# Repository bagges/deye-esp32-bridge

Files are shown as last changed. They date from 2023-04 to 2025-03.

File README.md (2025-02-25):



# deye-esp32-bridge

This PCB and Software is used to create a board which communicates with your Deye/Sunsynk inverter and also the BMS of your battery (SeplosBMS and PaceBMS are supported for now).



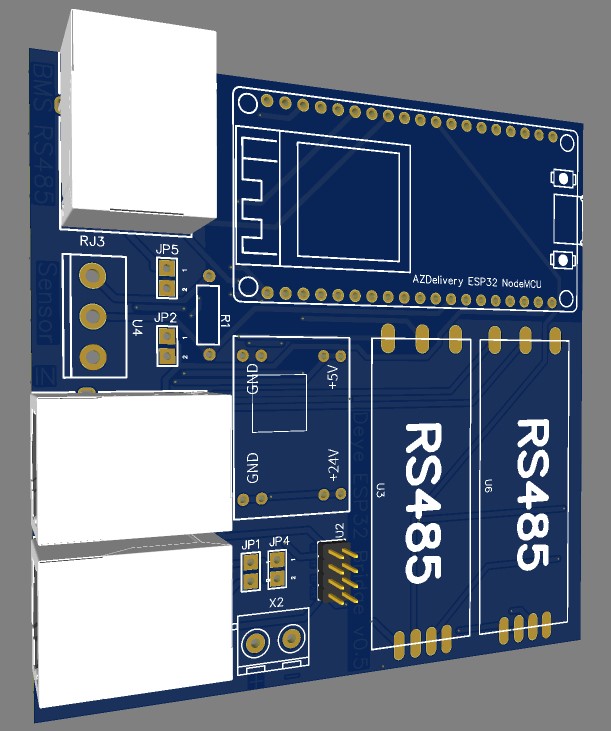
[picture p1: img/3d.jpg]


# BOM
 - [PCB (designed with easyeda and produced by jlcpcb)](https://www.makeiton.de/produkt-kategorie/bauteile/)
 - [AZDelivery ESP32 Dev v4](https://amzn.to/41Sd0v4)
 - [2x RS485 Serial Converter](https://amzn.to/3L1OmBq)
 - [DC/DC Step Down Module](https://amzn.to/3oFFiur)
 - [3x RJ45 connectors](https://amzn.to/3AqmPo8)
 - [12V din rail power supply](https://amzn.to/3VNIEYH)

# Prepare RS485 Serial Converter
Make sure that your RS485 converter is terminated by about 120R. 
Measure the resistance between B- and A+. Should be something between 110-130 Ohms. 
If you cannot measure any resistance, you need to shorten the the two small pins next to the B- connector. 
On my boards it was labled with R13.

# Deye Setup
 - Goto Advanced Function and set to Slave and Modbus SN 01

# Flash ESP32
 - Adapt your wifi settings in the secrets.yaml
 - Connect your PC to the micro USB and run: ```esphome run deye-esp32-bridge.yaml```

# Wiring
 - Connect any 7-24V DC source to the screw headers (do not use CN2 PINS 7+8 from deye inverter, they only work for about 100mA). Make sure that JP2 is closed.
 - As an alternative you can connect directly to the USB of the ESP32. Make sure that JP2 is not closed. This method makes often problems with the RS485 connection.
 - Connect your inverters BMS RJ45 to the CAN IN RJ45 of the PCB.
 - If you want to connect your inverter and BMS via CAN. connect your BMS to the BMS IN RJ45 of the PCB.
 - Connect your Seplos BMS to RJ3
 - I used RJ45 cables without shield connected to the RJ45 connector

## Component Description
| Component | Function |
|---|---|
| JP1 | If closed, connects GND from Deye to GND of the BMS |
| JP2 | If closed, connects the DCDC Converter to the ESP32 |
| JP4 | If closed, connects GND from Deye to GND of the PCB |
| JP5 | If closed, connects GND from the BMS to GND of the PCB |
| U2 | Additional general purpose I/O / GND / 5V / 3V3 |
| R1 | Optional resistor, needed if connecting DS18B20 to U4  |
| RJ1 | Connects to the BMS port of Deye |
| RJ2 | Connects to the CAN Port of the BMS |
| RJ3 | Connects to the RS485 Port of the BMS |

# Software
 - The esphome configuration file for deye is based on the work of klatremis (https://github.com/klatremis/esphome-for-deye)
 - The esphome configuration file for seplos is based on the work of syssi (https://github.com/syssi/esphome-seplos-bms)
 
# Disclaimer

This repository contains files for demonstration purposes only. Use the files on your own risk. I am not responsible for any damage!

# License

Shield: [][cc-by-nc-sa]

This work is licensed under a
[Creative Commons Attribution-NonCommercial-ShareAlike 4.0 International License][cc-by-nc-sa].

[][cc-by-nc-sa]

[cc-by-nc-sa]: http://creativecommons.org/licenses/by-nc-sa/4.0/
[cc-by-nc-sa-image]: https://licensebuttons.net/l/by-nc-sa/4.0/88x31.png
[cc-by-nc-sa-shield]: https://img.shields.io/badge/License-CC%20BY--NC--SA%204.0-lightgrey.svg

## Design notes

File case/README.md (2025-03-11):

# Modified 3D Printed Case

I had a few changes that i wanted to do to the Case so i turned the stl's of the existing case into CAD files and made a few changes that some might like aswell and i think having options is better then not having them :D. So here you go. Below are some Pictures.

### Changes to the Bottom of the Case
The PCB's that I ordered were 2mm thick instead of the Standard ~1.5mm. So i adjusted the depth where the pcb sits in to accomodate the 2mm thick PCB's.

Additionally I like to use Heatset inserts instead of screwing into the plastic, but the previous holes were only 4mm. So i adjusted them to 4.7mm which is the perfect size for M3 Heatsets when printed in ABS. Should still work for PLA and other Materials.
### Changes to the Top of the Case
There was not really anything that needed changing, but I was not a fan of the MARK 4 Label and i wanted to lable the diffrent ports instead. So that's what i did, I added lables for the 3 Rj45 Ports, the Temperature sensor, + and - for the power Terminal aswell as a USB logo for the USB port of the ESP32.
To Fit the Lables a bit better, I made the cutouts for the screw Terminals a little bit smaller. Everything is still accessible.

You have a few options of how to print this:
- Print only the 'top.stl' and have the text and logo's engraved into the printed piece.
- Print it in multiple colors by importing all the stl files from the Folder 'MultiColor options' aswell as the top.stl from the 'top' folder at the same time and selecting 'yes' when asked if you want to import all the files as a Single Object with multiple Parts. If you do this, the logos will be automatically placed in the engraved parts of the case. If you do not do this, the logos will all just be put into the center of the slicer. (only works when the slicer is setup for Multi color Printing, otherwise it does not ask the question). This way you can give each of the Lables a diffrent color, i find this the best option to use myself.
- Print it in multiple colors by using the file 'top_with_labels_multicolor_split_to_parts.stl' from the subfolder 'Single_multicolor_file' under 'MultiColor options' and right clicking it in the Slicer and click 'split to multiple parts' and coloring each file as you like. This has the problem/benefit depending on how you view it, that it splits the text into its individual letters, so you could color each letter the word "BMS" in a diffrent color. Might be useful for someone, but i find this a bit cumbersome, but this way you only need to download one file instead of multiple.

I made a Picture as an example, with alot of colors, i only printed it in Black with green Logos, but you can customize or print in whatever combination of colors as you like.

### Multicolor
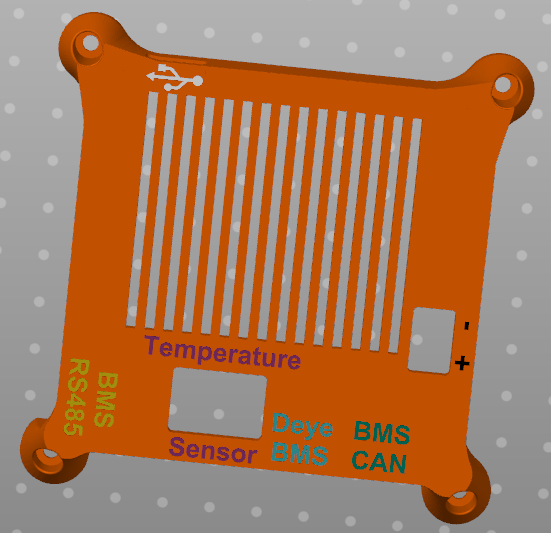
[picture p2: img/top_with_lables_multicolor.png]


### No Color, just engraved
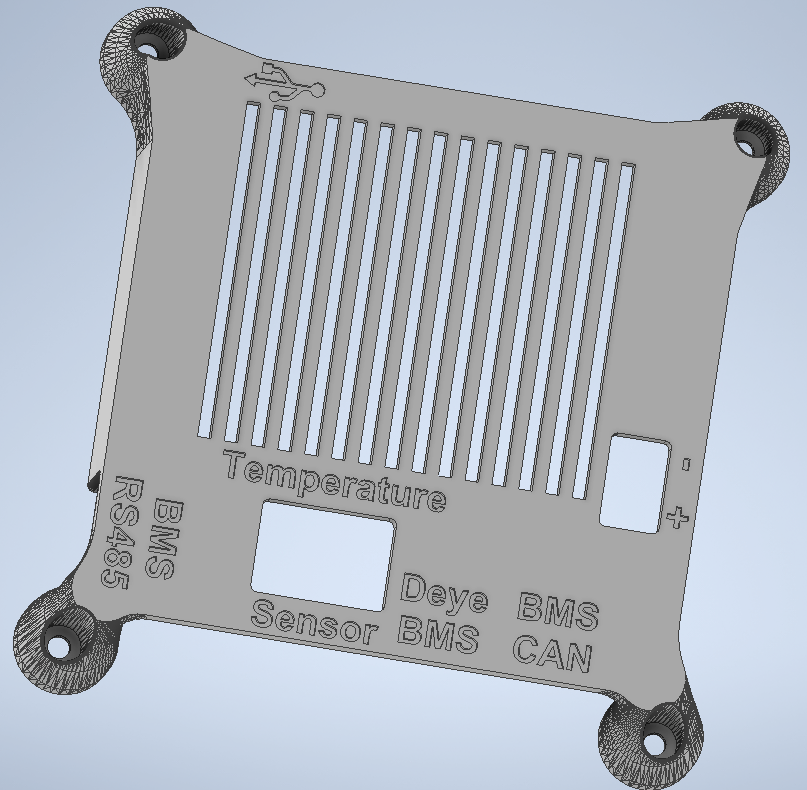
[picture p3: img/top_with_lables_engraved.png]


##### Case modified by:
- [xF4m3](https://github.com/xF4m3 "xF4m3")

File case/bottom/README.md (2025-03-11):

# Bottom Part of the Case for standard thickness PCB's

This is probably the bottom part of the case most of you will be printing, this is for standard size PCB's with a thickness of ~1.5mm.

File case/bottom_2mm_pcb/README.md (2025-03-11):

# Bottom Part of the Case for 2mm thick PCB's

In case your PCB does not have the standard thickness of ~1.5mm you can use this version to accomodate a 2mm thick PCB.

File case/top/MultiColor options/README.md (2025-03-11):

# MultiColor with Multiple Files

Stl's in this folder are all the Text and Logos. To use them you also need the top.stl fle together with all the stl's in this folder. Below is a description of how to do the Multicolored print.

- Print it in multiple colors by importing all the stl files from this folder aswell as the "top.stl" file from a folder higher up at the same time and selecting 'yes' when asked if you want to import all the files as a Single Object with multiple Parts. If you do this, the logos will be automatically placed in the engraved parts of the case. If you do not do this, the logos will all just be put into the center of the slicer and aligning will be difficult. (this only works when the slicer is setup for Multi color Printing, otherwise it does not ask the question). This way you can give each of the Lables a diffrent color, i find this the best option to use myself.

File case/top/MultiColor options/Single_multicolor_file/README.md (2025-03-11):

# Single Multicolor File

This file includes everything, the top.stl and all the logo and text stls as one object. See below for how to Print this with multiple colors.

- Print it in multiple colors by using the file 'top_with_labels_multicolor_split_to_parts.stl' from the this Folder and right clicking it in the Slicer and click 'split to multiple parts' and coloring each file as you like. This has the problem/benefit depending on how you view it, that it splits the text into its individual letters, so you could color each letter the word "BMS" in a diffrent color. Might be useful for someone, but i find this a bit cumbersome, but this way you only need to download one file instead of multiple.

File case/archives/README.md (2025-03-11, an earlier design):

# Previous version of the Case without any labes. It does have a "Mark 4" Logo instead.

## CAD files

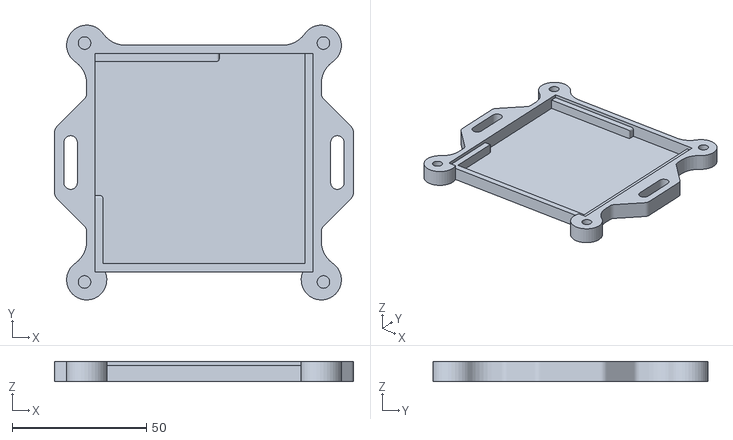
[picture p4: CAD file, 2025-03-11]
case/bottom/bottom.stl
111.4 x 102.4 x 7.50

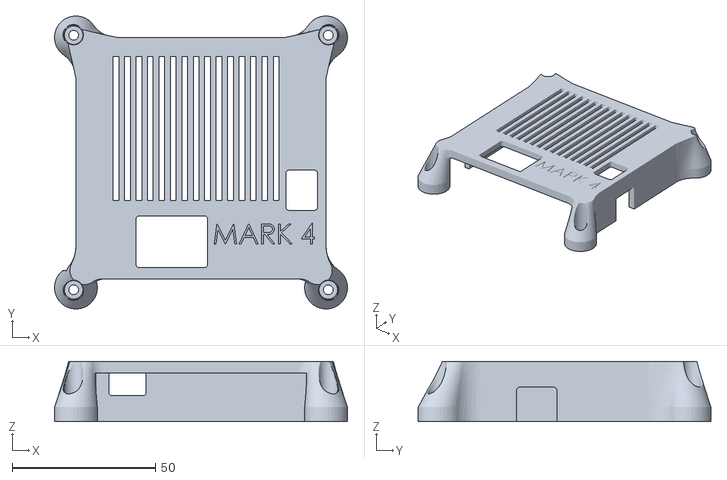
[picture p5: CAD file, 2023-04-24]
case/top.STL
102.4 x 102.4 x 21.0

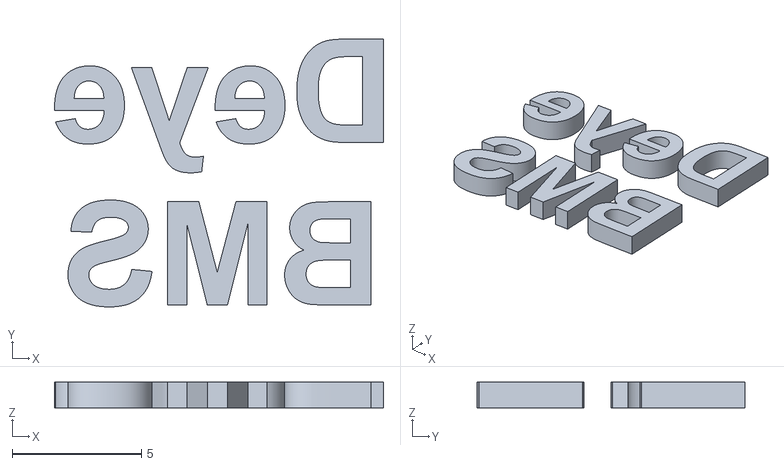
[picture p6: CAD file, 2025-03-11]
case/top/MultiColor options/deye_bms_text.stl
12.7 x 10.4 x 1.00

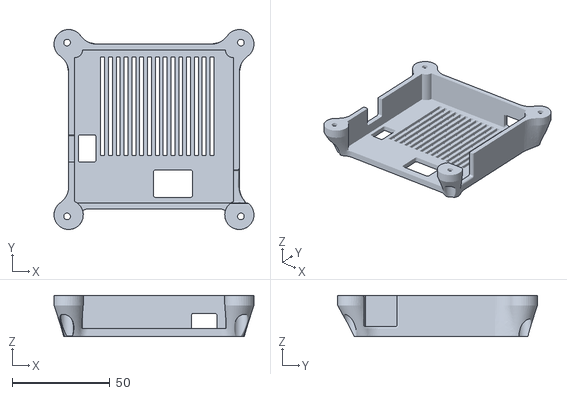
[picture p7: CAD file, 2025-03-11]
case/top/top.stl
102.4 x 102.4 x 21.0

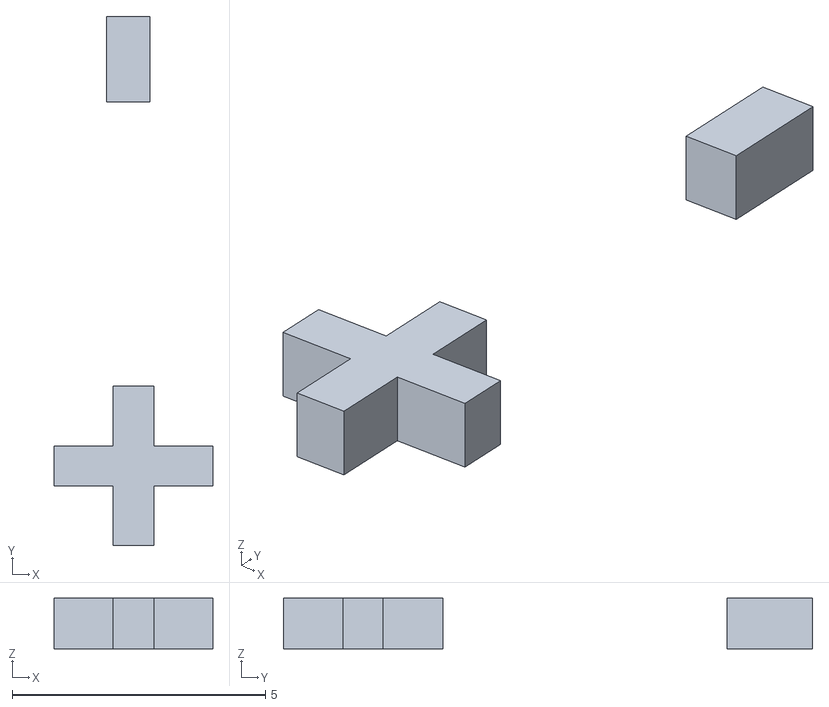
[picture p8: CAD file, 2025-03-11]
case/top/MultiColor options/24V_logo.stl
3.14 x 10.4 x 1.00

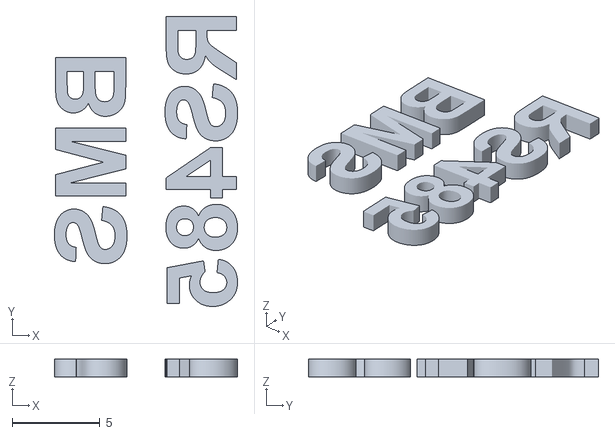
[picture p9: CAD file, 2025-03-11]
case/top/MultiColor options/bms_rs485_text.stl
10.4 x 16.5 x 1.00

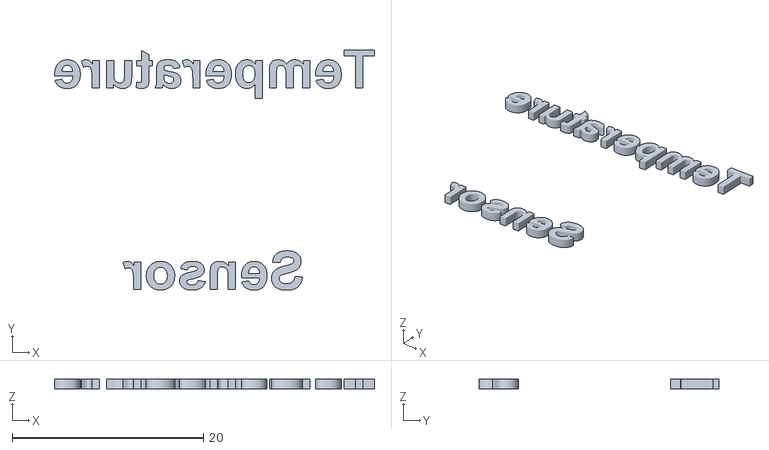
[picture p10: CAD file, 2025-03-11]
case/top/MultiColor options/temperature_sensor_text.stl
33.5 x 25.2 x 1.00

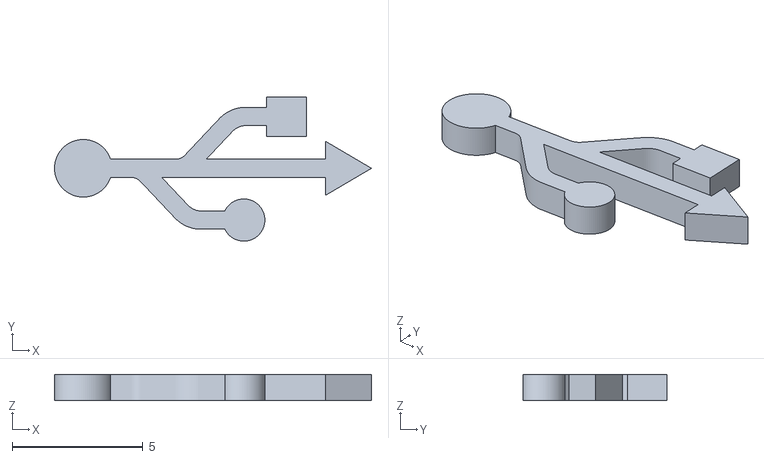
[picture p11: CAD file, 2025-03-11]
case/top/MultiColor options/usb_logo.stl
12.1 x 5.51 x 1.00

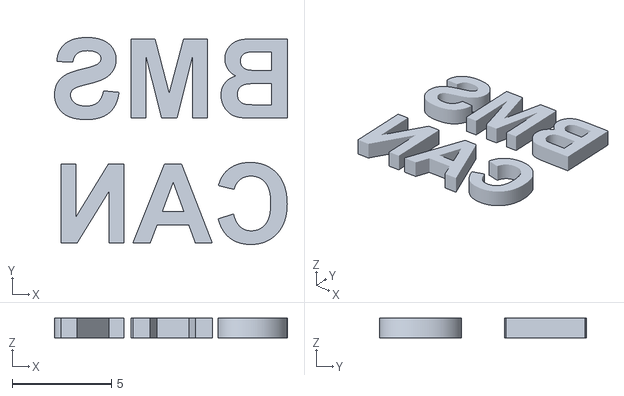
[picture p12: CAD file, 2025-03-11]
case/top/MultiColor options/bms_can_text.stl
11.7 x 10.4 x 1.00

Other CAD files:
case/bottom/CAD/bottom_standard_pcb.step
case/bottom_2mm_pcb/CAD/bottom_2mm_pcb.step
case/bottom.STL
case/archives/bottom.STL
case/bottom_2mm_pcb/bottom_2mm_pcb.stl

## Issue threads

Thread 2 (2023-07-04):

PCB Board

Gisbert1, 2023-07-04:
Hi,
where can I order a PCB (designed with easyeda and produced by jlcpcb) or get the files to Order it myself?
Best Regards
Gisbert

Gisbert1, 2023-07-04:
I found Gerber files in the source code. I believe that's what I'm looking for.

bagges, 2023-07-04:
I do not sell the board. You can order from jlcpcb with the gerber files from the repo

Closed 2023-07-04.

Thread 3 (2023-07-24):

Support for Pace BMS

engel75, 2023-07-24:
Hi,

I really like to test the esp32-bridge with my Deye inverter and my battery. My battery uses a Pace BMS  (P16s200A) and syssi just pushed his esp32 pace BMS config:
https://github.com/syssi/esphome-pace-bms

I never merged different modbus contollers in one configuration. Is it possible to add Pace BMS support to the bridge?

bagges, 2023-07-24:
Hi, I just checked syssi's repo. Looks like Pace has the same pinout as Seplos so it should work. I cannot test it as I do not have a Pace BMS. You just need to adapt the esphome config.

bagges, 2023-07-27:
I added an example for PACE BMS: https://github.com/bagges/deye-esp32-bridge/blob/main/deye-esp32-bridge-pace.yaml

You need to enable modbus first on Pace BMS. refer to: https://github.com/syssi/esphome-pace-bms#esphome-pace-bms

engel75, 2023-08-03:
Thank you for adding this example!

I am almost finished with the PCB board, but I would like to clarify some questions I have regarding your wiring description:

"Connect any 7-24V DC source to the screw headers (do not use CN2 PINS 7+8 from deye inverter, they only work for about 100mA). Make sure that JP2 is closed."

screw headers = X2

"Connect your inverters BMS RJ45 to the CAN IN RJ45 of the PCB."

CAN IN RJ45 = RJ1
On my Deye inverter this is the port labeled "BMS", right?

"If you want to connect your inverter and BMS via CAN. connect your BMS to the BMS IN RJ45 of the PCB."

BMS IN RJ45 = RJ2

Checking the PCB layout, this will just connect my BMS with the inverter and the PCB is just the "bridge" regarding cabling, right?

"I used RJ45 cables without shield connected to the RJ45 connector"

So no ethernet cable but some very simple RJ45 "phone" cable?

"Connect your Seplos BMS to RJ3"

So the R485 Port of my Battery is now connected to the PCB. But I still need the battery to be connected to my Deye inverter.
I got two options:

A: R485 is used via RJ1 (this option is true anyway...)
B: This is done via that "CAN bridge" (RJ1 -> RJ2)

So B could be useful if, eg. the PCB board fails?

Pls correct my if I am wrong.

engel75, 2023-08-04:
Any idea where to get the U2 (HB PH8 20024PB2GOP)?
It is just for serial debugging, right? So I might leave it blank?

bagges, 2023-08-04:
> Any idea where to get the U2 (HB PH8 20024PB2GOP)? It is just for serial debugging, right? So I might leave it blank?

This is just for further extensions. you can leave it blank.

bagges, 2023-08-04:
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

Yes

> "Connect your inverters BMS RJ45 to the CAN IN RJ45 of the PCB."
>
> CAN IN RJ45 = RJ1 On my Deye inverter this is the port labeled "BMS", right?

Yes

> "If you want to connect your inverter and BMS via CAN. connect your BMS to the BMS IN RJ45 of the PCB."
>
> BMS IN RJ45 = RJ2

To BMS CAN, yes

> Checking the PCB layout, this will just connect my BMS with the inverter and the PCB is just the "bridge" regarding cabling, right?

Yes

> "I used RJ45 cables without shield connected to the RJ45 connector"
>
> So no ethernet cable but some very simple RJ45 "phone" cable?

Also not all ethernet cables to have a shield. In the latest layout the shield of the rj45 jack is not connected, so shielded cable should also make no problems.

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

You cannot connect your Deye via RS485 and this PCB.

> So B could be useful if, eg. the PCB board fails?

This is the only way to connect your BMS with Deye. Otherwise you have to use BatV/Bat% settings in Deye.

> Pls correct my if I am wrong.

engel75, 2023-08-09:
I finished the board and flashed the esp32. Looks promising right now. I am still waiting for my 12V power supply and the lifepo4 battery. I ordered your very nice looking housing as well, but the screws are driving me crazy :)
I was not able to find any screw that would fit. Any hints regarding the screws to close the housing?

bagges, 2023-08-09:
It is designed to fit those: https://www.amazon.de/gp/product/B0B51MFXZQ/

Then you can just use normal m3 screws.

engel75, 2023-08-09:
Ok I removed all the Pace BMS stuff to only log the Deye but I get:

`INFO OTA successful
INFO Successfully uploaded program.
INFO Starting log output from esphome-web-4da3ec.local using esphome API
INFO Successfully connected to esphome-web-4da3ec.local
[23:22:38][I][app:102]: ESPHome version 2023.7.1 compiled on Aug  9 2023, 23:22:11
[23:22:42][W][modbus_controller:113]: Duplicate modbus command found: type=0x3 address=130 count=1
[23:22:42][W][modbus_controller:113]: Duplicate modbus command found: type=0x3 address=145 count=2
[23:22:42][W][modbus_controller:113]: Duplicate modbus command found: type=0x3 address=148 count=12
[23:22:42][W][modbus_controller:113]: Duplicate modbus command found: type=0x3 address=166 count=12
[23:22:42][W][modbus_controller:113]: Duplicate modbus command found: type=0x3 address=500 count=1
[23:22:42][W][modbus_controller:113]: Duplicate modbus command found: type=0x3 address=502 count=1
[23:22:42][W][modbus_controller:113]: Duplicate modbus command found: type=0x3 address=524 count=1
[23:22:42][W][modbus_controller:113]: Duplicate modbus command found: type=0x3 address=527 count=3
[23:22:42][W][modbus_controller:113]: Duplicate modbus command found: type=0x3 address=534 count=2
[23:22:42][W][modbus_controller:113]: Duplicate modbus command found: type=0x3 address=541 count=1
[23:22:42][W][modbus_controller:113]: Duplicate modbus command found: type=0x3 address=548 count=1
[23:22:42][W][modbus_controller:113]: Duplicate modbus command found: type=0x3 address=551 count=8
[23:22:42][W][modbus_controller:113]: Duplicate modbus command found: type=0x3 address=586 count=3
[23:22:42][W][modbus_controller:113]: Duplicate modbus command found: type=0x3 address=590 count=3
[23:22:42][W][modbus_controller:113]: Duplicate modbus command found: type=0x3 address=598 count=3
[23:22:42][W][modbus_controller:113]: Duplicate modbus command found: type=0x3 address=604 count=4
[23:22:42][W][modbus_controller:113]: Duplicate modbus command found: type=0x3 address=616 count=4
[23:22:42][W][modbus_controller:113]: Duplicate modbus command found: type=0x3 address=625 count=1
[23:22:42][W][modbus_controller:113]: Duplicate modbus command found: type=0x3 address=630 count=3
[23:22:42][W][modbus_controller:113]: Duplicate modbus command found: type=0x3 address=638 count=1
[23:22:42][W][modbus_controller:113]: Duplicate modbus command found: type=0x3 address=653 count=1
[23:22:42][W][modbus_controller:113]: Duplicate modbus command found: type=0x3 address=655 count=1
[23:22:42][W][modbus_controller:113]: Duplicate modbus command found: type=0x3 address=672 count=2
[23:22:42][W][modbus_controller:113]: Duplicate modbus command found: type=0x3 address=676 count=4
[23:22:42][W][component:204]: Component modbus_controller took a long time for an operation (0.21 s).
[23:22:42][W][component:205]: Components should block for at most 20-30ms.
[23:22:50][W][modbus_controller:113]: Duplicate modbus command found: type=0x3 address=65 count=1
[23:22:50][W][modbus_controller:113]: Duplicate modbus command found: type=0x3 address=99 count=3
[23:22:50][W][modbus_controller:113]: Duplicate modbus command found: type=0x3 address=108 count=2`

Any idea?

bagges, 2023-08-09:
Bad wiring, no termination resistor, bad power supply.

engel75, 2023-08-10:
> Bad wiring, no termination resistor, bad power supply.

looks like the deye did not "save" the modbus SN01. It was still set to 00. Got all values now! Awesome!

bagges, 2023-08-10:
Does PaceBMS now also work?

Gisbert1, 2023-08-30:
Dear Markus,

I finalized the board yesterday evening, I measured 118 Ohm on RS485 boards, and started to connect the board to my Delongtop HS51200 battery and DEYE 12kW inverter. PACE_MODBUS was selectet with the BMS tool and the RS485-Port of the battery is connected to RJ3.In Advanced Settings in the DEYE, Modbus 01 Slave is selectet.

The communication of the board to the battery is working and the data are published via MQTT. So far so good.

When I plugged the BMS port (see photo with yellow cable) on the inverter either to RJ1 or RJ2, I got a communication error "W31 Battery_comm_warn". The battery is still loaded by the DEYE but there is no communication.

According to the DEYE approved battery list, the battery should be connected with the CAN port (at the battery) with inverter setup 00 - this is working fine.

What's about the other port in the DEYE named ModBUS? Shall I use this port for the connection to RJ1 or RJ2 and leave the cable Battery/CAN - DEYE/BMS where it is?

Regards
Gisbert

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

Gisbert1, 2023-08-30:
One more question, do I need to close the jumpers 1 and 4. Currently they are open.

Gisbert1, 2023-08-30:
Dear Markus,

thanks for your explanation, now it works.

For those who might have the same experience as me, the "RJ1 is to connect your Inverter to the board (reads data from the inverter over RS485)" which is in my case the BMS port of the inverter (see the picture above).

The second thing was that I gave up to early when the wiring was alright but the DEYE has still the communation warning and the warning signal. After a minute the warning stopped and everthing works normal.

Many Thanks
and Cheers
Gisbert

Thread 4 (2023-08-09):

MQTT

Gisbert1, 2023-08-09:
As far as I understand, the information is provided in a webbrowser when typing the IP address of the ESP32.
I want the data in my house automatisation FHEM. Is it possible to publish the information via MQTT? Or is there any other way to provide the information to my house automatisation?

bagges, 2023-08-09:
For mqtt you have to provide mqtt config in the yaml. That should then work with fhem, iobroker,...

Gisbert1, 2023-08-09:
Hi bagges,
for me it's more than difficult, at my level even impossible, to add MQTT to your code (I'm using credentials with my MQTT broker).
Could you help me with the implementation and an example? If it's then necessary to put the code multiple times at different lines in your code, I could do that.
Regards and Greetings from NRW to Saarland
Gisbert

bagges, 2023-08-09:
You just have to add this one time to your yaml:

```
mqtt:
  broker: IP
  port: PORT
  topic_prefix: PREFIX (opt.)
  username: USER (opt.)
  password: PASSW (opt.)
```

Gisbert1, 2023-08-10:
Hello bagges,
MQTT works now with your project. The next steps for me are to solder everthing together and to add the board to the DEYE and the battery.
Many Thanks and Greetings
Gisbert

Closed 2023-08-10.

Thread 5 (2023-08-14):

[feature] external fan control

engel75, 2023-08-14:
Hi,
what about adding support to control "external" 12V PWM fans to cool the Deye Inverter based on a temperature sensor? My Deye 12k is quite noisy on sunny days. To me, it sounds like those fans are not very well controlled. What about adding additional 12V PWM Fans (without opening the inverter!) to the bottom or top of the inverter, controlled by the ESP32 based on the temperature of the Deye case or cooling fins?

bagges, 2023-08-28:
Yeah good idea. Will think about adding such a feature.

bagges, 2023-09-08:
I checked this and it should already be possible with external 12V power supply. I ordered some fans, will try in the next days.

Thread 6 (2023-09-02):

Log: Time	level	Tag	Message

Gisbert1, 2023-09-02:
Hello Markus,

I receive in the Webbrowser all the time logs like the following:

Time	level	Tag	Message
17:43:50	[W]	[component:205]
Components should block for at most 20-30ms.
17:43:51	[W]	[component:204]
Component modbus_controller took a long time for an operation (0.10 s).
17:43:51	[W]	[component:205]
Components should block for at most 20-30ms.
17:43:51	[W]	[component:204]
Component modbus_controller took a long time for an operation (0.06 s).
17:43:51	[W]	[component:205]
Components should block for at most 20-30ms.
17:43:59	[W]	[component:204]
Component modbus_controller took a long time for an operation (0.08 s).

As I use MQTT (and currently do not know how to connect ESPHome with my house automation FHEM), I'm fine with the selected small numbers of topics of about 25 messages with each update - I use 10 seconds between each update. My MQTT broker has irregular connection issues which is very likely not connected to this project.

In the web browser it's possible to set values or select on/off. It would be helpfull for me if I could also publish MQTT Messages to the ESP32. Is there a simple way to implement that to your code, to receive messages in the ESP32 and set values or switch on/off?

Regards
Gisbert

bagges, 2023-09-06:
You could create a subscribe sensor (https://esphome.io/components/sensor/mqtt_subscribe.html) and then do an automation with on_value, check the value and push it to your desired action.

Closed 2023-09-14.

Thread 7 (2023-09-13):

RJ45 Jack

pollierer, 2023-09-13:
Awesome project, thank you for sharing!
I'm about to do my own version of a PCB and I found you use exactly the RJ45 jack I have at home in spare. I could not find any footprint for this parts, so I wanted to ask if you could provide your footprints. That would be great!
I use KiCad but this should be no issue.
When I finish the project I can share my experience with connecting my Deye Sun-8k..lp03..eu
Thank you!

bagges, 2023-09-13:
How does your own version differ? I used the easyeda model from this site: https://www.lcsc.com/product-detail/Ethernet-Connectors-Modular-Connectors-RJ45-RJ11_Shenzhen-Kinghelm-Elec-KH-RJ45-59-8P8C_C2683358.html

pollierer, 2023-09-14:
Thanks for the link @bagges ! :)
My Version will be more simple, I only need one rs485 and I want to add a downstepper module and my own power jack, also I want to add a ESP32 in D1 mini format, that´s the main reason I do my own one. Btw I like that you´re using jumpers, very versatile - will propably steal this idea for future projects ;)

Closed 2023-09-14.

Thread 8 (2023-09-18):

no bug - but explanation for pcb

AndyMuc72, 2023-09-18:
Hello,

I love your project. I ordered the pcb and started soldering. I also checked for the 120 Ohm on the 485_2_TTLs.
But I don't understand what are the connectors U4 (Sensors written on the PCB) and what is U2? Is it a connector?
Is it possible to show also a picture of the finished soldered pcb?

thank you
Andy

bagges, 2023-09-18:
U4 is to connect for example a ds18b20 temperature sensor. U2 is just a connector for some I/O and Power/GND pins if you want to do some extensions (LCD for example).

Finished PCB I can send a picture afterwards.

AndyMuc72, 2023-09-18:
that makes sense. Where can I get this connector U2 in Germany and what is its name?
I have a Pylontech Battery, so I don't know if this project is useful for me. Did you think about implementing Pylontech?

Did you print a case?

bagges, 2023-09-18:
U2 is just for normal jumper wires, I do not know if there is a special connector for this. Pylontech has a different pinout on the rj45, this does not work.
Yes I printed the case from this repo.

AndyMuc72, 2023-09-28:
Ich habe gesehen, dass die Pylontech Akkus die RS485 Pins auf der anderen Seite haben. Wenn man ein spezielles Kabel macht, dann sollte man die Werte auch auslesen können, oder (und natürlich die Modbus Adressen anpassen).
Ich benutze den Adapter erstmal für den Deye.
Ich habe aber festgestellt, dass ich sehr viele CRC Fehler habe und auch ab und zu falsche Werte bekomme (z.B. "${device_type}-PV2 Power" liefert bei aktueller Leistung 2000W plötzlich einen Wert von 65000). Hier musste ich jetzt mit LAMBDA Filtern arbeiten, um die Werte zu ignorieren.
Hast du da irgendeine Idee, an was das liegen kann?

bagges, 2023-09-28:
Are you using an ESP32 or ESP8266?
CRC errors often occur because of bad power supply or bad bus termination.

AndyMuc72, 2023-09-28:
It is a ESP32. That is a good hint. I use an USB power supply and there is a Raspi 4 on this power supply too. I am not physically there right now. When I am there I will change it and see what will happen. Thank you

bagges, 2023-10-03:
Checkout the README, JP2 must not be closed when USB power connected. USB power supply often make problems.

AndyMuc72, 2023-10-03:
ok, thanx, I just read it, too. I will try a separate power supply next. all jumpers are open.

Closed 2023-10-03.

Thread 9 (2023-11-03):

[Possible issue] DC-DC Converter inner pins not matching and Documentation request

xF4m3, 2023-11-03:
Hey, not sure if that is an issue in general orwith the DC-DC Converter that i received.

For me only the outer 4 holes are close to identical(not perfect), but the 4 inner holes of the Converter do not fit, i can only get them to show a tiny bit if i shift the board a bit so that all 8 holes atleast are visible in the slightes. I do know that its not needed since the 4 inner and 4 outer holes are just a "mirror" of each other. But it would be nice if that could be double checked.

Of course it could also be diffrences in the DC-DC converters, but i used the ones that were linked in the BOM.

Additionally, i don't want to open a second issue just for that, but it would be nice if you could make a short description what each of the Jumpers do. Only JP2 is mentioned so far. maybe a small Table with all jumpers/connectors/headers and what they are for would be a nice addition.

bagges, 2023-11-03:
The DC-DC Converter I received, have a perfect fit with the PCB. Could you post a picture?

I updated the readme to contain a table with component description: https://github.com/bagges/deye-esp32-bridge/commit/7357dff866de68883b9de0463fbbb4cc4467fbf4

xF4m3, 2023-11-04:
I have already soldered everything and tried to align everything even if that means a hole is only visible 1/3, just tried to flush it with solder.
But i just made some photos. You can see that the distance from inner to outer is about 2.5mm while on the dc-dc converter its about 3mm(only a rough measurement, as seen in the photos).

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

bagges, 2023-11-04:
Really strange, mine do perfect fit RM2.54...

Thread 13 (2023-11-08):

Update

Gisbert1, 2023-11-08:
Hi Markus,
when I started an update of the file "deye-esp32-bridge-pace.yaml" I got the following respond: "Update Failed: Wrong Magic Byte". The only change was in line 11:
modbus_update_interval: "8s" instead of modbus_update_interval: "10s" which I have currently.
What is the right way to update changes to the ESP32?
Best Regards
Gisbert

bagges, 2023-11-29:
Revert the changes and try again. your change seems correct.

Closed 2023-12-12.

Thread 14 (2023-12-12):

Darstellung der Werte in HA

ThiloGa, 2023-12-12:
Moin,

dank der hier geleisteten Arbeit bekomme ich Werte in HA.

Allerdings bekomme ich bei PV Total Power keine Verlaufskurve, sondern
einen sich farblich verändernden Balken.

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

An welche Schraube wäre hier zu drehen?
Folgefehler ist sicherlich, dass sich dieser Wert und der Outputpowerwert von OpenDTU per Helper nicht addieren lassen.

Danke

Grüsse

ThiloGa, 2024-02-12:
> Should work now

Better, but not... :-)

Now i can sum up the power values of deye und opendtu, but here...

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

... is nothing :-O

after click on "Verlauf" there is graph

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

ThiloGa, 2024-02-12:
> > Should work now
>
> Better, but not... :-)

Further investigation shows, that PV[1|2] Power is working fine, so the problem must be buildiung the sum of PV[1|2] Power...

bagges, 2024-02-12:
Hm, I need to investigate to this. Maybe setting force_update to true could fix this.

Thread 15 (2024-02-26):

Lithium or Bat% vs. BatV

Gisbert1, 2024-02-26:
Hi Bagges,

in your code deye-esp32-bridge.yaml, the BatV mode is commented out.
NEEDED IF YOU USE BatV%
NEEDED IF YOU USE Lithium or Bat%
Do I need to make a decision before I flash the code to the ESP32 or can I use both in the code at the same time? Of course not in the Deye - there is only one mode at one time possible.

I have a second question:
Currently I have no battery and later I will have a battery with a JKBMS which will not have any data communication to the Deye or your board - but I still want to use your board and your code. Can I simply delete any parts of the code with is related to "bms" or "seplos", ...? For the Deye the modbus_id is modbus1. Can I have a modbus_id modbus1 and no modbus0 or do I need to start always with modbus0?

I would be great if you could publish a version deye-esp32-bridge-batv.yaml (no BMS but charging mode BatV in the Deye menu).

Best Regards
Gisbert

bagges, 2024-02-26:
You can add both to the code before you flash the ESP32 but I do not know what happens if you change values when different mode is choosen in the inverter.

You can just delete everything. But you could also add those configuration: https://github.com/syssi/esphome-jk-bms/ and crimp an adapter to fit the pinout of the jkbms.

modbus0, modbus1,... it's just a name. can be anything.

Closed 2024-02-26.

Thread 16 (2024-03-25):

Two PACE-BMS + Deye

m1k3f15h, 2024-03-25:
Hey Guys,

Did somebody tested this with 2 PACE-BMS (on one Modbus) + 1 Deye?
Is the ESP32 "Strong and Fast" enouch?

greetings from Austria
Mike

bagges, 2024-05-22:
Did you have success with this? I do not have PACE BMS, cannot test...

S-t-e-p-s-i, 2024-05-26:
Hello Mike I am also interested in, if you were successful.

@bagges really great board and project for the DEYE setup!! 
I started from scratch three weeks ago and knew I could work with many data points in HA. Really impressive. 

My setup: Deye Sun10k/FM-Solar stackable 2 × 10 kWh battery storage.

S-t-e-p-s-i, 2024-06-03:
Maybe I can place a question about the possible setup here...

I get all the relevant data from the Deye and Pace BMS via the bridge, works without any problems so far.

In order to read the values from the second battery pack, I have looped the RS485 through to the bridge. I can access the data of the respective battery banks individually via the address 0x01 / 0x02, but I can't manage to process the data for both banks in the Yaml code via a reciver/converter.

With regard to master and slave processing of the converters, it seems to me that these are limited in this technical function?
Or may i understood the coding not fully ...

https://esphome.io/components/modbus_controller.html

would then mean that I need a separate converter for the second battery bank.
If someone can give a helpful tip whether it can be processed with a corresponding adjustment in the Yaml would be really great.

Greetings Stefan

esphome:
  name: deye-bridge

esp32:
  board: az-delivery-devkit-v4
  framework:
    type: arduino

# Enable logging
logger:
  level: INFO

substitutions:
  bms_name_1: Batterypack1
  bms_name_2: Batterypack2
  modbus_update_interval: "8s"
  settings_skipped_updates: "10"
  query_throttle: "50ms"
  device_name: deye_bridge
  device_type: sun10k_bridge
  device_description: "Esphome component for Deye sun-10k-sg04lp3"
  modbus_controller_id: sg04lp3

# Enable Home Assistant API
api:
  encryption:
    key: xxxx

ota:
  password: xxxx

wifi:
  ssid: !secret wifi_ssid
  password: !secret wifi_password

  # Enable fallback hotspot (captive portal) in case wifi connection fails
  ap:
    ssid: "Deye-Bridge Fallback Hotspot"
    password: xxx

captive_portal:

uart:
  - id: uartdeye
    tx_pin: 27
    rx_pin: 26
    baud_rate: 9600
  - id: uartpace
    tx_pin: 17
    rx_pin: 16
    baud_rate: 9600
    debug:
      direction: BOTH
      dummy_receiver: false

modbus_controller:
  - id: ${modbus_controller_id}
    address: 0x01
    modbus_id: modbus1
    setup_priority: -10
    update_interval: ${modbus_update_interval}
    command_throttle: ${query_throttle}
  - id: bms0
    # Slave address 0x01
    address: 0x01
    modbus_id: modbus0
    command_throttle: 200ms
    update_interval: 6s
# - id: bms1
#    # Slave address 0x02
    #address: 0x02
    #modbus_id: modbus2
    #command_throttle: 300ms
    #update_interval: 8s

modbus:
  - id: modbus1
    uart_id: uartdeye
  - id: modbus0
    uart_id: uartpace
    send_wait_time: 200ms
  #- id: modbus2
  #  uart_id: uartpace
  #  send_wait_time: 300ms
time:
  - platform: sntp
    id: sntp_time
    timezone: Europe/Berlin
    servers:
    - pool.ntp.org

Sensor:      #(eg. how i tried it.....)

  #  15  Cell voltage 1                        2 byte   R  uint16  mV
  - platform: modbus_controller
    modbus_controller_id: bms0
    name: "${bms_name_1} cell voltage 1"
    address: 15
    register_type: holding
    value_type: U_WORD
    unit_of_measurement: "V"
    state_class: measurement
    accuracy_decimals: 3
    filters:
      - multiply: 0.001
  - platform: modbus_controller
    modbus_controller_id: bms1
    name: "${bms_name_2} cell voltage 1"
    address: 15
    register_type: holding
    value_type: U_WORD
    unit_of_measurement: "V"
    state_class: measurement
    accuracy_decimals: 3
    filters:
      - multiply: 0.001

m1k3f15h, 2024-06-06:
Hy Stefan

This is my YML for 1 Deye and 2 Batterys.. maybe this helps you.
[ess.txt](https://github.com/user-attachments/files/15605577/ess.txt)

Mike

bagges, 2025-03-11:
closing because no more information was provided.

Closed 2025-03-11.

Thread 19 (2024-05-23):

ESP32 hängt sich nach ein paar Tagen auf

Lembi203, 2024-05-23:
Nach ein paar Tagen ( 1-7 ) werden die Entitäten unavailable und der ESP geht offline, ich habe genau die verlinkten Komponenten bestellt, aber es läuft nicht zuverlässig.

Logs hab ich keine weil es so unregelmäßig passiert und der ESP offline geht.

Ich habe schon mehrere ESP vom gleichen Typ an Modbus Zählern usw, das funktioniert zuverlässig.

bagges, 2024-05-23:
Welche ESPHome Version?
Auch das gleiche Netzteil verwendet?

bagges, 2024-05-28:
Ohne Logs wird das echt schwierig. Kannst du die Netzteile mal verlinken? Über USB geht nicht, der Spannungswandler bringt nicht genug für alle Komponenten.

m1k3f15h, 2024-06-07:
Was für einen ESP / Board hast du?
mike

Lembi203, 2024-06-07:
Das verlinkte von AZDelivery

m1k3f15h, 2024-06-07:
wo verlinkt?

Lembi203, 2024-06-07:
Den der in der Readme verlinkt ist.
[AZDelivery ESP32 Dev v4](https://amzn.to/41Sd0v4)

m1k3f15h, 2024-06-07:
okay.. da läuft es bei mir jetzt zum testen...

bei dem BOARD: [https://www.amazon.de/AZDelivery-Bluetooth-Internet-Entwicklungsboard-kompatibel/dp/B08BTLYSTM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](url) hab ich das problem, dass der alle paar tage aufgibt...

sven-s, 2024-09-07:
Ich habe auch das Problem, dass sich das Board immer wieder offline meldet. Hast du den Kondensator an die Versorgungsleitung des ESP32 gehängt? Also an Plus und Masse?

bagges, 2024-09-08:
> Ich habe auch das Problem, dass sich das Board immer wieder offline meldet. Hast du den Kondensator an die Versorgungsleitung des ESP32 gehängt? Also an Plus und Masse?

Auf dem Step Down sind Kondensatoren drauf. Ich habe sonst nichts zusätzlich. Wie versorgst du denn mit Strom? Ich hatte das Problem, wenn ich entweder direkt über den ESP gehe (der Spannungsregler liefert nicht genug Saft), oder ein Netzteil mit zu wenig Saft an dem DCDC hatte.

sven-s, 2024-09-08:
Hatte zuerst eine 15 Watt USB Netzteil, nun aber das Poppstar Netzteil für Hutschiene 12V DC 1,25A 15 W (Input 100-240 V AC 50/60 Hz). Habe noch einen Elko direkt vor den Step Down gehängt, aber leider kein Erfolg.

Bei mir zeigt sich das folgendermassen:

- Ping erfolgt nicht durchgehend, und auch die UI ist zeitweise nicht erreichbar.
- Das MQTT Topic geht auf Status Offline

Das Log in der UI sieht so aus:

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

Kann ich noch weitere Logs auslesen? Kann der ESP evtl. zu heiss werden und daher offline gehen bzw. neustarten?

bagges, 2024-09-08:
Ping erfolgt nicht durchgehen: hast du einfach schlechtes WLAN? Es scheint auch was mit deiner Modbus Verbindung nicht zu stimmen. Die crc Fehler habe ich nicht.

sven-s, 2024-09-08:
Habe in der Garage einen eigenen Unifi AP. Der ist nur 3 m Luftlinie entfernt, von daher würde das erstmal ausschließen.

bagges, 2024-09-08:
Check trotzdem mal ob der ESP mit diesem verbunden ist. Hatte schon ähnliche Konstellation und musste den ESP auf einen AP locken...

sven-s, 2024-09-08:
Ja, der ist mit dem AP verbunden mit -46dBm. Habe den jetzt auch gelockt. Ping kommt aber nicht durchgehend. Werde mal mit der aktuellsten esphome Version flashen.

sven-s, 2024-09-08:
Habe auch noch einen anderen ESP an dem Unifi AP per Wifi. Der lässt sich durchgehend anpingen... das muss an etwas anderem liegen.

m1k3f15h, 2024-09-09:
> Ich habe auch das Problem, dass sich das Board immer wieder offline meldet. Hast du den Kondensator an die Versorgungsleitung des ESP32 gehängt? Also an Plus und Masse?

Servus,

Ja ich hab den Kondensator so nahe wie möglich am DevBoard an die Versorgungsspannung gelötet.. seit dem keine Probleme mehr :)

sven-s, 2024-09-10:
So, habe nochmals alles gecheckt, Kabel getauscht, Widerstand vom RS485 gemessen und so weiter. Hat alles nicht geholfen.

Über das Log habe ich immer wieder die Meldung gehabt:

```
[20:44:52][I][app:100]: ESPHome version 2024.8.3 compiled on Sep  8 2024, 23:20:30
[20:44:57]E (28403) task_wdt: Task watchdog got triggered. The following tasks did not reset the watchdog in time:
[20:44:57]E (28403) task_wdt:  - loopTask (CPU 1)
[20:44:57]E (28403) task_wdt: Tasks currently running:
[20:44:57]E (28403) task_wdt: CPU 0: IDLE
[20:44:57]E (28403) task_wdt: CPU 1: IDLE
[20:44:57]E (28403) task_wdt: Aborting.
[20:44:57]
[20:44:57]abort() was called at PC 0x4010bbbc on core 0
[20:44:57]
[20:44:57]
[20:44:57]Backtrace:0x400838f9:0x3ffbe9cc |<-CORRUPTED
WARNING Found stack trace! Trying to decode it
WARNING Decoded 0x400838f9: panic_abort at /Users/ficeto/Desktop/ESP32/ESP32S2/esp-idf-public/components/esp_system/panic.c:402
[20:44:57]
[20:44:57]
[20:44:57]
[20:44:57]
[20:44:57]ELF file SHA256: 0000000000000000
[20:44:57]
[20:44:57]Rebooting...
[20:44:57]ets Jul 29 2019 12:21:46
[20:44:57]
[20:44:57]rst:0xc (SW_CPU_RESET),boot:0x13 (SPI_FAST_FLASH_BOOT)
[20:44:57]configsip: 0, SPIWP:0xee
[20:44:57]clk_drv:0x00,q_drv:0x00,d_drv:0x00,cs0_drv:0x00,hd_drv:0x00,wp_drv:0x00
[20:44:57]mode:DIO, clock div:2
[20:44:57]load:0x3fff0030,len:1184
[20:44:57]load:0x40078000,len:13132
[20:44:57]load:0x40080400,len:3036
[20:44:57]entry 0x400805e4
```

Ich nutze die PACE yaml, da ich einen Deye mit Gobel Akku habe.

Dann habe ich mal einige Configs (ca. 20) aus dem Pace Bereich auskommentiert, wie:

```
  # # 100  Environment OT protection             2 byte  RW   int16  0.1 ℃
  # - platform: modbus_controller
  #   modbus_controller_id: bms0
  #   name: "${bms_name} environment overtemperature protection"
  #   use_write_multiple: true
  #   address: 100
  #   register_type: holding
  #   value_type: S_WORD
  #   lambda: "return  x * 0.1f; "
  #   write_lambda: "return x * 10.0f;"
  #   min_value: -200.0
  #   max_value: 200.0
  #   step: 0.1
  #   mode: box
  #   unit_of_measurement: "°C"
```

Seitdem läuft das deutlich besser. Die Werte kommen durchgehend und der Ping ist auch die ganze Zeit da.

Von daher gehe ich mal davon aus, dass der ESP mit der Anzahl der Register nicht zurechtgekommen ist.

bagges, 2024-09-10:
Der PACE Hinweis ist nicht ganz unwichtig -.-. Ich hab leider kein PACE und kann das nicht verifizieren. Statt Configs rauszunehmen kannst du auch versuchen das ```modbus_update_interval``` höher zu setzen.

bagges, 2025-03-11:
Ich schließe das Issue hier mal. Falls es noch Probleme gibt bitte nochmal schreiben.

Closed 2025-03-11.

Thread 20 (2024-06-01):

Gehäuse, welche Schrauben sind da vorgesehen?

ThiloGa, 2024-06-01:
Kein Code issue... :-)

welche Schrauben sollen eigentlich das Case zusammenhalten?

Hab in meiner grossen Schraubenkiste nix passendes gefunden... ;-)

Grüsse
Thilo

S-t-e-p-s-i, 2024-06-02:
Hallo Thilo,

nach meinem Verständnis kannst du da Gewindebuchsen einpressen schau mal bei Amazon und Co nach Ruthex Gewindebuchsen für 3D Druck. So mache ich das zumindest bei meinen Teilen die auch länger halten sollen.

[ruthex](https://www.ruthex.de/)

Gruß Stefan

bagges, 2024-06-02:
Wie Stefan schon sagt. Ich nutze diese: https://amzn.eu/d/4xWvvk3 und schmelze sie mit dem Lötkolben ein.

ThiloGa, 2024-06-04:
Hi Stefan,

> nach meinem Verständnis kannst du da Gewindebuchsen einpressen schau mal bei Amazon und Co nach Ruthex Gewindebuchsen für 3D Druck. So mache ich das zumindest bei meinen Teilen die auch länger halten sollen.

Danke für die Infos. Was zum 3D-Druck gelernt.

>
> [ruthex](https://www.ruthex.de/)

Jetzt gibts da nur so grosse PE, brauche nur die 4 Stück.

Gibts ne Möglichkeit, dass du mir ein paar gegen Unkostenerstattung in einen Umschlag steckst?

Grüsse
Thilo

bagges, 2024-06-04:
@ThiloGa Schick mir n Euro über den Donate Button und ich schick dir n paar zu. Schreib deine Adresse ins Kommentarfeld.

Closed 2024-06-02.

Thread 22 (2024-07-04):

Communication between deye and JK

sarzyk, 2024-07-04:
Hi is there any chance to make communication between dey battery RW-M6.1 and JK BMS 2A16S20P?
Thanks for reply

bagges, 2024-09-09:
Theoretically if they both use rs485 and have the same pinout it is possible by changing the yaml

Closed 2024-09-09.

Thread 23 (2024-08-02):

Summer winter time changeover

PVAnfaenger, 2024-08-02:
Hello everyone,
since the last time conversion still have an open point!
And that is that the Deye did not do this automatically. Now the question, can this be controlled via the Modbus? From address 62-64 the time is in the communication protocol. However, I don't know how to do this, how to combine 6 bytes in esphome into one variable and then describe it correctly.

Can someone help me here?

bagges, 2024-09-09:
As a starting point, here is how you can read the sensor:

`text_sensor:
  - platform: modbus_controller
    modbus_controller_id: ${modbus_controller_id}
    name: "${device_type}-system time"
    id: ${device_type}_system_time
    register_type: holding
    address: 62
    register_count: 3
    response_size: 6
    lambda: |-
      int jahr = (int)data[item->offset]+2000;
      int monat = (int)data[item->offset + 1];
      int tag = (int)data[item->offset + 2];
      int stunde = (int)data[item->offset + 3];
      int minute = (int)data[item->offset + 4];
      int sekunde = (int)data[item->offset + 5];
      char buffer[20];
      sprintf(buffer, "%d-%d-%d %d:%d:%d", jahr, monat, tag, stunde, minute, sekunde);
      return {buffer};`

Gives you:

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

Gisbert1, 2024-09-11:
Hi bagges,

your code works well and gives the current time of the DEYE.
I tried to search for a code to write a new date/time to the DEYE but my knowledge is by far too low.
To get always 4 or 2 digest for the date/time, the code could be:
...

PVAnfaenger, 2024-10-24:
I would be very interested in that too.

geronet1, 2025-02-13:
Solution, you can press the time sync button in HA or use the on_time logic:

```
substitutions:
  esphome_name: deye                                                 #name in ESPhome
	modbus_controller_id: sg04lp3

time:
  - platform: homeassistant
    id: esptime
  - platform: sntp
    on_time:
      - seconds: 0
        minutes: 0
        hours: 6
        days_of_week: MON
        then:
          - button.press: ${esphome_name}_time_sync

modbus:
  id: modbus1
# flow_control_pin: 4 #for use when you use a rs485 board without auto flow control. Like the rs485 max board.

modbus_controller:
  - id: ${modbus_controller_id}
    address: 0x1
    modbus_id: modbus1
    setup_priority: -10
    update_interval: ${intervall}
    #command_throttle: "50ms"

button:
  - platform: template
    name: ${name} time sync
    id: ${esphome_name}_time_sync
    icon: "mdi:clock-outline"
    on_press:
      then:
        - lambda: |-
            esphome::modbus_controller::ModbusController *controller = id(sg04lp3);

            time_t now = ::time(nullptr);
            struct tm *time_info = ::localtime(&now);
            int seconds = time_info->tm_sec;
            int minutes = time_info->tm_min;
            int hour = time_info->tm_hour;
            int day = time_info->tm_mday;
            int month = time_info->tm_mon + 1;
            int year = time_info->tm_year + 1900; /* The number of years since 1900   */

            // if there is no internet connection localtime returns year 70
            if (year != 1970)
            {
              std::vector<uint16_t> rtc_data = {uint16_t(((year-2000) << 8) | month), uint16_t((day << 8) | hour), uint16_t((minutes << 8) | seconds)};
              // Create a Modbus command item with the time information as the payload
              esphome::modbus_controller::ModbusCommandItem set_rtc_command =
                esphome::modbus_controller::ModbusCommandItem::create_write_multiple_command(controller, 62, rtc_data.size(), rtc_data);
              // Submit the command to the send queue
              controller->queue_command(set_rtc_command);
              ESP_LOGI("ModbusLambda", "Deye RTC set to %02d:%02d:%02d %02d.%02d.%04d", hour, minutes, seconds, day, month, year);
            }
            else
              ESP_LOGW("ModbusLambda", "RTC sync failed");

```

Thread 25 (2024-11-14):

[BatteryMode] maximum battery discharge current not always reset

bagges, 2024-11-14:
From time to time the battery discharge current is not reset to the previous value

tingeltanglbob, 2024-12-26:
I had the problem that although the Fix25 switched to Hold mode, it continued drawing 100A from the battery. I changed the code as shown in the file

[deye_esp32_bridge fix25 changed.txt](https://github.com/user-attachments/files/18254127/deye_esp32_bridge.fix25.changed.txt)

bagges, 2024-12-26:
@tingeltanglbob you just swaped lines [171](https://github.com/bagges/deye-esp32-bridge/blob/70bf9b45dd3bea3daef79f55c63ee801dec437eb/deye-esp32-bridge.yaml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) and 172 right? which makes totally sense, but I cannot belive that this fixes the issue...

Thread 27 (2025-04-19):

EASUN SMG II with Peace BMS

MBRetrofit, 2025-04-19:
Can you help me to integrate into your project the Easun SMG II inverter with the Pace BMS?

The Easun integration over RS232 is here, tested and working,

https://github.com/syssi/esphome-smg-ii/blob/main/esp32-example.yaml

bagges, 2025-04-19:
What do you mean with integrate? Actually the board does not support RS232.

MBRetrofit, 2025-04-21:
Yes, I want to replace Deye sensors and settings with Easun SMG II. My DIY battery hase Pace BMS already.

bagges, 2025-04-27:
closing here because of the discussion in https://github.com/bagges/deye-esp32-bridge/issues/26

Closed 2025-04-27.

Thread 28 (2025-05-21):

New Energy Sensors for Pacex BMS

MBRetrofit, 2025-05-21:
Based on Power sensor

 ```  - platform: modbus_controller
    modbus_controller_id: bms0
    name: "${bms_name} power"~~~

I renamed this Power sensor as RAW - as this can be positive or negative and I created 2 more for Charging Power and Discharging Power and another 2 ones for Charging Energy and Discharging Energy.

````
# 1. Charging Power (W) - Template Sensor
- platform: template
  id: charging_power  # Required for reference
  name: "${device1} Charging Power"
  unit_of_measurement: "W"
  device_class: power
  state_class: measurement
  lambda: |-
    float power = id(bms_power_raw).state;
    return (power > 0) ? power : 0.0f;

# 2. Discharging Power (W) - Template Sensor
- platform: template
  id: discharging_power  # Required for reference
  name: "${device1} Discharging Power"
  unit_of_measurement: "W"
  device_class: power
  state_class: measurement
  lambda: |-
    float power = id(bms_power_raw).state;
    return (power < 0) ? -power : 0.0f;

# Charging Energy (kWh)
- platform: integration
  name: "bms_charging_energy"
  sensor: charging_power          # Refers to the template sensor's ID
  time_unit: "h"                 # Required! Options: "s", "min", "h", "d"
  unit_of_measurement: "kWh"
  device_class: energy
  state_class: total_increasing
  accuracy_decimals: 3
  filters:
    - multiply: 0.001            # Converts W → kW (1 kWh = 1 kW * 1 h)

# Discharging Energy (kWh)
- platform: integration
  name: "bms_discharging_energy"
  sensor: discharging_power       # Refers to the template sensor's ID
  time_unit: "h"                  # Must match the unit above
  unit_of_measurement: "kWh"
  device_class: energy
  state_class: total_increasing
  accuracy_decimals: 3
  filters:
    - multiply: 0.001
````

Based on Charging/Discharging Energy a Utility Meter can be added on ````configuration.yaml```

````utility_meter:
  daily_charging_energy:
    source: sensor.bms_charging_energy
    cycle: daily
  daily_discharging_energy:
    source: sensor.bms_discharging_energy
    cycle: daily

````

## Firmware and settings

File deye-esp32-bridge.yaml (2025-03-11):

esphome:
  name: deye-esp32
  platform: ESP32
  board: nodemcu-32s

logger:
  level: INFO

globals:
   - id: helper_discharge_current
     type: int
     restore_value: yes
     initial_value: '100'
   - id: max_soc
     type: float
     restore_value: yes
     initial_value: '0.0'
   - id: target_soc
     type: float
     restore_value: yes
     initial_value: '30.0'
substitutions:
  bms_name: seplos-bms
  modbus_update_interval: "8s"
  settings_skipped_updates: "10"
  query_throttle: "50ms"
  device_name: deye
  device_type: sun10k
  device_description: "Esphome component for Deye sun-10k-sg04lp3"
  modbus_controller_id: sg04lp3
  external_components_source: github://syssi/esphome-seplos-bms@main
  
api:

captive_portal:

external_components:
  - source: ${external_components_source}
    refresh: 0s

uart:
  - id: uartdeye
    tx_pin: 27
    rx_pin: 26
    baud_rate: 9600
  - id: uartseplos
    tx_pin: 17
    rx_pin: 16
    baud_rate: 19200
    rx_buffer_size: 384
    debug:

modbus_controller:
  - id: ${modbus_controller_id}
    address: 0x01
    modbus_id: modbus1
    setup_priority: -10
    update_interval: ${modbus_update_interval}
    command_throttle: ${query_throttle}

seplos_bms:
  id: bms0
  address: 0x00
  protocol_version: 0x20
  seplos_modbus_id: modbus0
  update_interval: 10s

seplos_modbus:
  id: modbus0
  uart_id: uartseplos
  rx_timeout: 150ms

modbus:
  id: modbus1
  uart_id: uartdeye

ota:
  platform: esphome
  password: ""

wifi:
  ssid: !secret wifi_ssid
  password: !secret wifi_password

web_server:
  port: 80

time:
  - platform: sntp
    id: sntp_time
    timezone: Europe/Berlin
    servers:
    - pool.ntp.org
    on_time:
      - seconds: 0
        minutes: 0
        hours: 23
        days_of_week: MON-SUN
        then:
          - if:
              condition:
                lambda: |-
                  return id(batterylife_enabled).state;
              then:
                - lambda: |-
                    float new_target = id(target_soc);
                    if (id(max_soc) >= 95.0) {
                      new_target = new_target - 5.0;
                    } else if (id(max_soc) < 85.0) {
                      new_target = new_target + 5.0;
                    }
                    if (new_target > 85.0) {
                      new_target = 85.0;
                    }
                    if (new_target < 30.0) {
                      new_target = 30.0;
                    }
                    id(target_soc) = new_target;
                    id(max_soc) = 0.0;
                - number.set:
                    id: ${device_type}_Time_point_1_capacity
                    value: !lambda |-
                        return id(target_soc);
                - delay: 1s
                - number.set:
                    id: ${device_type}_Time_point_2_capacity
                    value: !lambda |-
                        return id(target_soc);
                - delay: 1s
                - number.set:
                    id: ${device_type}_Time_point_3_capacity
                    value: !lambda |-
                        return id(target_soc);
                - delay: 1s
                - number.set:
                    id: ${device_type}_Time_point_4_capacity
                    value: !lambda |-
                        return id(target_soc);
                - delay: 1s
                - number.set:
                    id: ${device_type}_Time_point_5_capacity
                    value: !lambda |-
                        return id(target_soc);
                - delay: 1s
                - number.set:
                    id: ${device_type}_Time_point_6_capacity
                    value: !lambda |-
                        return id(target_soc);
select:
  - platform: template
    name: BatteryMode
    id: batterymode
    options:
     - "Normal"
     - "Hold"
     - "Charge"
    initial_option: "Normal"
    optimistic: true
    on_value:
      then:
        - number.set:
            id: ${device_type}_Maximum_battery_discharge_current
            value: !lambda |-
              if (id(batterymode).state == "Normal") {
                ESP_LOGI("Battery Mode", "Mode: %s with current of: %dA", "Normal", abs(id(helper_discharge_current)));
                return abs(id(helper_discharge_current));
              } else if (id(batterymode).state == "Hold") {
                ESP_LOGI("Battery Mode", "Mode: %s with current of: %dA", "Hold", 5);
                return 5;
              } else if (id(batterymode).state == "Charge") {
                ESP_LOGD("Battery Mode", "Charge selected, not implemented!");
                return abs(id(helper_discharge_current));
              }
              return 5;
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

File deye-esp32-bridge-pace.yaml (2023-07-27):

esphome:
  name: deye-esp32
  platform: ESP32
  board: nodemcu-32s

logger:
  level: INFO

substitutions:
  bms_name: pace-bms
  modbus_update_interval: "8s"
  settings_skipped_updates: "10"
  query_throttle: "50ms"
  device_name: deye
  device_type: sun10k
  device_description: "Esphome component for Deye sun-10k-sg04lp3"
  modbus_controller_id: sg04lp3
  
api:

captive_portal:

uart:
  - id: uartdeye
    tx_pin: 27
    rx_pin: 26
    baud_rate: 9600
  - id: uartpace
    tx_pin: 17
    rx_pin: 16
    baud_rate: 9600
    debug:
      direction: BOTH
      dummy_receiver: false

modbus_controller:
  - id: ${modbus_controller_id}
    address: 0x01
    modbus_id: modbus1
    setup_priority: -10
    update_interval: ${modbus_update_interval}
    command_throttle: ${query_throttle}
  - id: bms0
    # Slave address 0x01
    address: 0x01
    modbus_id: modbus0
    command_throttle: 200ms
    update_interval: 10s
    
modbus:
  - id: modbus1
    uart_id: uartdeye
  - id: modbus0
    uart_id: uartpace
    send_wait_time: 200ms

ota:
  password: ""

wifi:
  ssid: !secret wifi_ssid
  password: !secret wifi_password

web_server:
  port: 80

time:
  - platform: sntp
    id: sntp_time
    timezone: Europe/Berlin
    servers:
    - pool.ntp.org
    
switch:
  - platform: restart
    name: "Restart ESP32-Deye Bridge"
  - platform: modbus_controller
    use_write_multiple: true
    modbus_controller_id: ${modbus_controller_id}
    name: ${device_type}_Solar_sell
    register_type: holding
    address: 145
    bitmask: 1
    entity_category: config
    icon: "mdi:toggle-switch"
 
  - platform: modbus_controller
    use_write_multiple: true
    modbus_controller_id: ${modbus_controller_id}
    name: ${device_type}-Grid_Charge
    register_type: holding
    address: 130
    bitmask: 1
    entity_category: config
    icon: "mdi:toggle-switch"
 
  - platform: modbus_controller  # Advanced peak shaving and valley filling function enabled
    use_write_multiple: true
    modbus_controller_id: ${modbus_controller_id}
    name: ${device_type}-Time of Use 
    id: ${device_type}_Time_of_Use
    register_type: holding
    address: 146
    bitmask: 1
    entity_category: config
    icon: "mdi:toggle-switch"
 
  - platform: modbus_controller  # Time point 1 charge enable - grid charging enable
    use_write_multiple: true
    modbus_controller_id: ${modbus_controller_id}
    name: ${device_type}-Time point 1 charge enable
    register_type: holding
    address: 172
    bitmask: 1   # 2 hvis man ønsker Gen charging enabel i sted for.
    entity_category: config
    icon: "mdi:toggle-switch"
 
  - platform: modbus_controller  # Time point 2 charge enable - grid charging enable
    use_write_multiple: true
    modbus_controller_id: ${modbus_controller_id}
    name: ${device_type}-Time point 2 charge enable
    register_type: holding
    address: 173
    bitmask: 1    # 2 hvis man ønsker Gen charging enabel i sted for.
    entity_category: config
    icon: "mdi:toggle-switch"
 
  - platform: modbus_controller  # Time point 3 charge enable - grid charging enable
    use_write_multiple: true
    modbus_controller_id: ${modbus_controller_id}
    name: ${device_type}-Time point 3 charge enable
    register_type: holding
    address: 174
    bitmask: 1    # 2 hvis man ønsker Gen charging enabel i sted for.
    entity_category: config
    icon: "mdi:toggle-switch"
 
  - platform: modbus_controller  # Time point 4 charge enable - grid charging enable
    use_write_multiple: true
    modbus_controller_id: ${modbus_controller_id}
    name: ${device_type}-Time point 4 charge enable
    register_type: holding
    address: 175
    bitmask: 1    # 2 hvis man ønsker Gen charging enabel i sted for.
    entity_category: config
    icon: "mdi:toggle-switch"
 
  - platform: modbus_controller  # Time point 5 charge enable - grid charging enable
    use_write_multiple: true
    modbus_controller_id: ${modbus_controller_id}
    name: ${device_type}-Time point 5 charge enable
    register_type: holding
    address: 176
    bitmask: 1    # 2 hvis man ønsker Gen charging enabel i sted for.
    entity_category: config
    icon: "mdi:toggle-switch"
 
  - platform: modbus_controller  # Time point 6 charge enable - grid charging enable
    use_write_multiple: true
    modbus_controller_id: ${modbus_controller_id}
    name: ${device_type}-Time point 6 charge enable
    register_type: holding
    address: 177
    bitmask: 1    # 2 hvis man ønsker Gen charging enabel i sted for.
    entity_category: config
    icon: "mdi:toggle-switch"
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

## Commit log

2023-03-10 updated design
    * increased track width
    * added canbus board
    * added sensor connection header
    * added copper area
    * added case
    [Drill_NPTH_Through.DRL, Drill_PTH_Through.DRL, Drill_PTH_Through_Via.DRL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]
2023-04-05 WIP: add seplos BMS
    [Drill_NPTH_Through.DRL, Drill_PTH_Through.DRL, Drill_PTH_Through_Via.DRL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]
2023-04-06 switch to debug-decoder branch
2023-04-23 update config for pcb v0.4
2023-04-24 v0.4 RC
    * remove canbus pcb
    * switch rs485 adapter. Using now adapter with automatic flow control.
    [Drill_NPTH_Through.DRL, Drill_PTH_Through.DRL, Drill_PTH_Through_Via.DRL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]
2023-05-05 Update deye-esp32-bridge.yaml
    added step: 5 parameter for Time_point_6_capacity (analog to others)
2023-05-29 add battery float, absorption and equalization voltages
2023-07-03 updated schematic, pcb and gerber files
    [Drill_NPTH_Through.DRL, Drill_PTH_Through.DRL, Drill_PTH_Through_Via.DRL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]
2023-07-27 add example for PACE BMS
2023-11-05 Modified 3D printed Case
    Bottom:
    - Adjusted for 2mm thick PCB's
    - Resized hole for M3 heatset inserts
    Top:
    - Made the cutouts above the screw terminals a bit smaller to better fit the Text. Everything is still accessible enough though.
    - Added lables for the RJ45 ports, screw Terminals and a logo for the USB port of the ESP32
    [bottom_2mm_pcb.step, bottom_2mm_pcb.stl, top_with_labels.stl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]
2023-11-06 Modified text size for better printing and restructured the folders to clear up confusion. Also added a few readme files to explain things better.
    [24V_logo.stl, bms_can_text.stl, bms_rs485_text.stl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]
2024-02-01 switch to lithium default
2024-02-01 first steps for evcc battery mode implementation
2024-06-01 Update and rename deye-seplosV3-neey.yaml to deye-seplosV3.yaml
    Removed neey code, cause of memory failure
    [deye-seplosV3.yaml]
2024-09-09 batterymode to 5A instead of 0A
2024-10-11 add battery life feature
2024-10-23 battery life bugfix. min soc was set even if feature switch was disabled
    [deye-esp32-bridge.yaml]
2025-03-11 minor change to battery life
2026-05-09 feat(esphome): add SoC-based charge current throttling
    - Add global variables to track charge throttle state and previous current
    - Add "SoC Charge Throttle enabled" switch to control throttling behavior
    - Add "SoC Throttle Threshold" number entity (50-100%, default 90%)
    - Add "SoC Throttle Charge Current" number entity (1-100A, default 5A)
    - Implement automatic charge current reduction when SoC reaches threshold
    - Implement automatic charge current restoration when SoC drops below threshold
    - Add logging for throttle activation, deactivation, and current settings
    - Include delays to prevent modbus bus contention during current adjustments
2026-10-23 feat(esphome): add Work Mode selector and improve SoC throttle logic
    - Add modbus_controller select entity for inverter Work Mode with three options (Selling First, Zero Export to Load, Zero Export to CT)
    - Improve charge current throttle state preservation by validating current value before saving to avoid corrupted state
    - Add hysteresis to SoC throttle deactivation condition (subtract 3% from threshold) to prevent rapid throttle toggling
    - Enhanced logging for SoC throttle operations to better track state transitions
2026-10-23 fix(esphome): update modbus helper function references
    - Replace deprecated `modbus_controller::word_from_hex_str` with `modbus::helpers::word_from_hex_str` in warning/protection/fault status parsing
    - Update Running Status lambda functions to use correct modbus helper namespace across all device configs
    - Apply changes to deye-esp32-bridge-pace.yaml, deye-esp32-bridge.yaml, deye-multi-seplosv3.yaml, and deye-seplosV3.yaml
    - Ensures compatibility with updated ESPHome modbus API
